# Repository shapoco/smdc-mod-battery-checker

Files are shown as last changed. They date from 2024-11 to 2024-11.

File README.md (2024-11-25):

# smdc-mod-battery-checker

[#SMD_Challenge](https://x.com/search?q=%23SMD_Challenge) の [基板](https://dominotech.blogspot.com/2024/08/smd-challenge-badge.html) を電池チェッカーに改造してみました。

## 機能

- プローブに接続された電池の残量を LED 5 個 x 点滅 4 段階 = 20 段階でレベル表示します。
- 1.5V、3V、3.7V、9V を判別し、それぞれの電圧範囲に応じてレベル表示します。
- プローブが開放状態のときは、起動後 3 秒間は自分自身の電池の電圧をレベル表示し、その後は元の SMD Challenge 基板と同様のアニメーションを表示します。

## 動作の様子

→ [x.com](https://twitter.com/shapoco/status/1860731428079857833)

## 回路

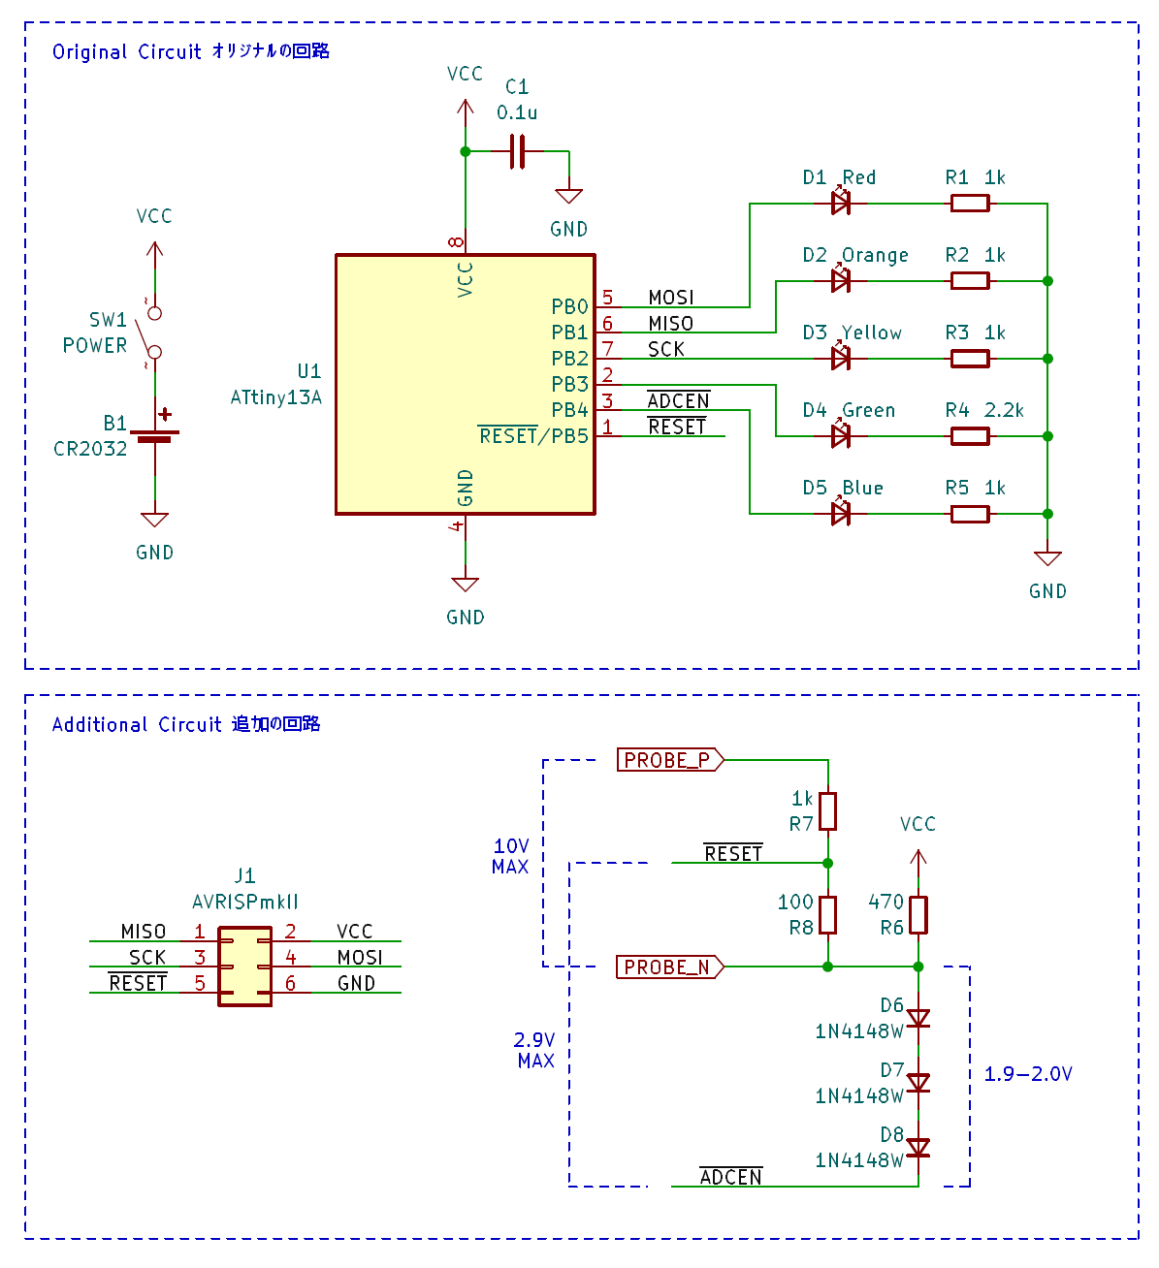
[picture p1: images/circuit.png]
回路図


## ヒューズ設定

600kHz で動作するように CKSEL=0b01 (4.8MHz)、CKDIV8=0b0 (クロックディバイダ有効) に設定しています。具体的な設定値は [fuse-write.ps1](firmware/tools/atprogram-win/fuse-write.ps1) を参照ください。

## ビルド手順

既に開発環境をお持ちであればそれを使って頂いてかまいません。

1. WSL に `gcc-avr`、`avr-libc`、`binutils-avr` をインストールします。
    - 参考: [avr-gcc と make だけで C/C++ AVR 環境構築 (ATmega328P) #Make - Qiita](https://qiita.com/BerandaMegane/items/740c75393b8fbfde5bed)
2. WSL 内で本リポジトリを clone し、`firmware/` の配下で `make` を実行します。
    - `firmware/build/battery_checker.elf` が生成されます。

## 書き込み手順

既に書き込み用のケーブルやツールをお持ちであればそれを使って頂いてかまいません。

1. Windows 環境に Microchip Studio をインストールします。
    - 書き込みに `C:\Program Files (x86)\Atmel\Studio\7.0\atbackend\atprogram.exe` を使用します。
2. AVRISP mkII を SMD Challenge 基板に接続します。
    - 環境によって `libusb-win32` のインストールが必要です。
3. WSL 内でリポジトリ配下の `firmware/` に移動します。
4. `make fuse-write` でヒューズを書き込みます。
5. `make flash-write` でプログラムを書き込みます。

## 仕組み

空き端子となっていた PB5 (RESET) に追加の回路を接続し、PB5/RESET と兼用の ADC0 を使って電圧を測定します。

PB5 にそのままアナログ電圧を入力すると電圧によってはリセットがかかってしまうので、1N4148W の順方向電圧降下 (Vf) x3 で 2V 程度の下駄を履かせ、そこを基準 (0V) として測定します。9V まで測定できるよう、抵抗分圧して入力しています。

1N4148W のカソードをそのまま GND に落とすと起動時の PB5 の電圧がリセット閾値の上限 (0.9Vcc) を下回ってしまいリセットが解除されない可能性があるため、GND ではなく PB4 に接続し、ADC0 を使う間は Low にドライブします。2V 程度ではリセットがかからないことを期待しています。

1N4148W の Vf は Vcc 電圧や環境温度で変動するため、起動時にプローブがオープンの状態で ADC 値を読み取り、1N4148W の I-V 特性から Vf と Vcc を推定します。Vcc や環境温度は時間とともに変化するため、プローブがオープンのときに定期的に更新します。

プローブに電池が接続されたときは Vf～Vcc の範囲をプローブ間の電圧に線形変換します。

## ダメなところ

- ATtiny13A のリセットの閾値電圧はデータシート上は 0.2Vcc ～ 0.9Vcc の範囲のどこかなので、そもそも使い方として正しくない。
- 1N4148W の個体差、Vcc 電圧、環境温度、PB4 の Low 電圧等の影響を受けるためデリケートすぎる。

----

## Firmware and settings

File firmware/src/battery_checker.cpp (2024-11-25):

#define F_CPU 600000ul

#include <avr/io.h>
#include <util/delay.h>
#include <stdint.h>

#define MIN(a, b) ((a) < (b) ? (a) : (b))
#define MAX(a, b) ((a) > (b) ? (a) : (b))
#define ROUND_DIV(a, b) (((a) + (b) / 2) / (b))

static constexpr int NUM_LEDS = 5;
static constexpr uint8_t LED_PIN_MASK = (1 << NUM_LEDS) - 1;

// 電圧の精度
static constexpr int VOLT_PREC = 12;
static constexpr uint16_t VOLT_ONE = 1ul << VOLT_PREC;

// レベル表示の階調
static constexpr uint8_t LEVEL_STEP = 4;
static constexpr uint8_t LEVEL_RANGE = NUM_LEDS * LEVEL_STEP;
static constexpr uint8_t LEVEL_MIN = 1;
static constexpr uint8_t LEVEL_MAX = LEVEL_MIN + LEVEL_RANGE - 1;

static constexpr uint16_t ADC_VCC = 1024;

// プローブ開放状態の ADC 値範囲
static constexpr uint16_t ADC_3XVF_MIN = 650; // VOLT_VCC_MAX に対応
static constexpr uint16_t ADC_3XVF_MAX = 774; // VOLT_VCC_MIN に対応

// VCC の電圧範囲
static constexpr uint16_t VOLT_VCC_MIN = 2.5f * VOLT_ONE; // ADC_3XVF_MAX に対応
static constexpr uint16_t VOLT_VCC_MAX = 3.2f * VOLT_ONE; // ADC_3XVF_MIN に対応

// プローブ開放判定の閾値電圧
static constexpr uint16_t VOLT_OPEN_MAX = 0.2f * VOLT_ONE;

// 1.5V 電池の電圧範囲
static constexpr uint16_t VOLT_1V5_MIN = 1.0f * VOLT_ONE;
static constexpr uint16_t VOLT_1V5_MAX = 1.6f * VOLT_ONE;

// 3V 電池の電圧範囲
static constexpr uint16_t VOLT_3V0_MIN = 2.5f * VOLT_ONE;
static constexpr uint16_t VOLT_3V0_MAX = 3.1f * VOLT_ONE;

// 3.7V 電池の電圧範囲
static constexpr uint16_t VOLT_3V7_MIN = 3.6f * VOLT_ONE;
static constexpr uint16_t VOLT_3V7_MAX = 4.2f * VOLT_ONE;

// 9V 電池の電圧範囲
static constexpr uint16_t VOLT_9V0_MIN = 7.0f * VOLT_ONE;
static constexpr uint16_t VOLT_9V0_MAX = 9.0f * VOLT_ONE;

// 入力分圧抵抗比
static constexpr uint8_t RDIV_HI = 10;
static constexpr uint8_t RDIV_LO = 1;

// 電圧レンジ
enum class VoltRange : uint8_t {
  OPEN,
  BAT_1V5,
  BAT_3V0,
  BAT_3V7,
  BAT_9V0,
};

// 開放時の ADC 値ヒストリ (Vcc 電圧推定用)
static constexpr uint8_t ADC_3XVF_SAMPLE_INTERVAL = 128;
static constexpr uint8_t ADC_3XVF_HISTORY_SIZE = 2;
static uint8_t adc3xVfSampleCounter = 0;
static uint16_t adc3xVfHistory[ADC_3XVF_HISTORY_SIZE];
static uint8_t adc3xVfHistoryIndex = 0;

// 電源電圧
static bool vccDetected = false;
static uint16_t voltVcc;

// 1N4148W の Vf * 3
static uint16_t volt3xVf;

// 電圧レンジヒストリ
static constexpr uint8_t RANGE_HISTORY_SIZE = 2;
static VoltRange rangeHistory[RANGE_HISTORY_SIZE];
static uint8_t rangeHistoryIndex = 0;
static VoltRange lastRange = VoltRange::OPEN;

// 各 LED のレベル値
static uint8_t ledValues[NUM_LEDS];

static constexpr int TARGET_FPS = 30;
static constexpr int LED_DRIVE_INTERVAL_MS = MAX(1, 1000 / TARGET_FPS / LEVEL_RANGE);
static constexpr int LED_BLINK_PERIOD_MS = 500;
static constexpr int LED_PHASE_STEP_CNTR_PERIOD = ROUND_DIV(LED_BLINK_PERIOD_MS, LED_DRIVE_INTERVAL_MS * LEVEL_RANGE);
static_assert(0 < LED_PHASE_STEP_CNTR_PERIOD && LED_PHASE_STEP_CNTR_PERIOD <= 255);
static uint8_t ledPhaseStepCntr = 0;
static uint8_t ledPhase = 0;

// 起動時の Vcc 電圧表示
static bool startup = true;

// 経過時間 (LED_BLINK_PERIOD_MS 単位, Max Hold)
static uint8_t tickCountMaxHold = 0;

// フリーランカウンタ (アニメーション用)
static uint8_t tickCountFreeRun = 0;

static void loop(void);
static void adc2Leds(uint16_t adcVal);
static void estimateVcc(uint16_t adcVal);
static uint16_t readAdcAverage(void);
static uint16_t readAdc(void);
static void volt2Leds(VoltRange range, uint16_t volt);
static void level2Leds(uint8_t level);
static void driveLeds(void);
static void lazyDelayMs(uint8_t duration);
static uint16_t unoffsetClip16u(uint16_t min, uint16_t range, uint16_t val);
static uint8_t cyclicIncr8u(uint8_t x, uint8_t period);

// x が 2 のべき乗か否か
#define IS_POW_OF_2_16U(x) \
    ((x) == (1u <<  0) || (x) == (1u <<  1) || (x) == (1u <<  2) || (x) == (1u <<  3) || \
     (x) == (1u <<  4) || (x) == (1u <<  5) || (x) == (1u <<  6) || (x) == (1u <<  7) || \
     (x) == (1u <<  8) || (x) == (1u <<  9) || (x) == (1u << 10) || (x) == (1u << 11) || \
     (x) == (1u << 12) || (x) == (1u << 13) || (x) == (1u << 14) || (x) == (1u << 15))

// x を 0 ～ (period-1) の間でサイクリックにインクリメントする
#define CYCLIC_INCR_8U(x, period) \
    (IS_POW_OF_2_16U(period) ? (((x) + 1) & ((period) - 1)) : cyclicIncr8u((x), (period)))

// 32bit x 16bit の乗算
#define mul32ux16u(a, b) ((uint32_t)(a) * (uint16_t)(b))

int main(void) {
    // GPIO 設定
    DDRB = LED_PIN_MASK; // PB0..4 を出力に設定
    PORTB = 0x00; // LOW 出力

    // ADC設定
    ADCSRA = 0b10000111;
    // [7]   ADEN  = 1    ADC有効
    // [6]   ADSC  = 0    ADC停止
    // [5]   ADATE = 0    オートトリガ無効
    // [4]   ADIF  = 0    割り込みなし
    // [3]   ADIE  = 0    割り込み無効
    // [2:0] ADPS  = 0    プリスケーラ: 128 (最大)
    ADMUX = 0x00;
    // [6]   REFS0 = 0    Vref = Vcc
    // [5]   ADLAR = 0    変換結果右寄せ
    // [1:0] MUX   = 0    ADC0 (PB5) 選択
    DIDR0 |= _BV(ADC0D); // ADC0 のデジタル入力無効化

    // ループ処理開始
    while(true) loop();
}

static void loop(void) {
    uint16_t adcVal = readAdcAverage();

    if (!vccDetected) { // Vcc 電圧推定前
        if (ADC_3XVF_MIN - 50 <= adcVal && adcVal < ADC_3XVF_MAX + 50) {
            // 初回測定値でヒストリを埋める
            for(int i = 0; i < ADC_3XVF_HISTORY_SIZE; i++) {
                adc3xVfHistory[i] = adcVal;
            }
            // 初期 Vcc 電圧推定
            estimateVcc(adcVal);
            vccDetected = true;
            tickCountMaxHold = 0;
            tickCountFreeRun = 0;
            ledPhase = 0;
        }
        else {
            level2Leds(ledPhase >= LEVEL_STEP / 2 ? 0 : LEVEL_MAX);
        }
    }
    else { // Vcc 電圧推定後
        adc2Leds(adcVal);
    }
    
    driveLeds();
}

// ADC 値から電圧に変換し LED に反映する
static void adc2Leds(uint16_t adcVal) {
    // ADC値から電圧へ変換
    uint16_t volt = mul32ux16u(adcVal, voltVcc) / ADC_VCC;
    volt = (volt >= volt3xVf) ? (volt - volt3xVf) : 0;
    volt = mul32ux16u(volt, RDIV_HI + RDIV_LO) / RDIV_LO;

    // レンジ判定 (雑でよいので 8bit に縮めて処理する)
    constexpr uint16_t VOLT_DIV = 1u << (VOLT_PREC - 4);
    constexpr uint8_t THRESH_1V5 = ROUND_DIV(VOLT_1V5_MAX + VOLT_3V0_MIN, 2 * VOLT_DIV);
    constexpr uint8_t THRESH_3V0 = ROUND_DIV(VOLT_3V0_MAX + VOLT_3V7_MIN, 2 * VOLT_DIV);
    constexpr uint8_t THRESH_3V7 = ROUND_DIV(VOLT_3V7_MAX + VOLT_9V0_MIN, 2 * VOLT_DIV);
    static_assert((15 * VOLT_ONE + VOLT_DIV / 2) / VOLT_DIV < 256);
    uint8_t voltDiv = ROUND_DIV(volt, VOLT_DIV);
    VoltRange range;
    if (volt < VOLT_OPEN_MAX) {
        range = VoltRange::OPEN;
    }
    else if (voltDiv <= THRESH_1V5) {
        range = VoltRange::BAT_1V5;
    }
    else if (voltDiv <= THRESH_3V0) {
        range = VoltRange::BAT_3V0;
    }
    else if (voltDiv <= THRESH_3V7) {
        range = VoltRange::BAT_3V7;
    }
    else {
        range = VoltRange::BAT_9V0;
    }

    // チャタリング除去
    bool stable = true;
    for (uint8_t i = 0; i < RANGE_HISTORY_SIZE; i++) {
        stable &= (range == rangeHistory[i]);
    }
    rangeHistory[rangeHistoryIndex] = range;
    rangeHistoryIndex = CYCLIC_INCR_8U(rangeHistoryIndex, RANGE_HISTORY_SIZE);
    if (!stable) return;
    
    // レンジの変化検出
    if (range != lastRange) {
        ledPhase = 0;
        tickCountMaxHold = 0;
        tickCountFreeRun = 0;
    }
    lastRange = range;

    // 表示の更新
    if (range == VoltRange::OPEN) { // 電池未接続時
        // Vcc 電圧や温度変化で基準電圧が変動するので定期的に更新する
        adc3xVfSampleCounter = CYCLIC_INCR_8U(adc3xVfSampleCounter, ADC_3XVF_SAMPLE_INTERVAL);
        if (adc3xVfSampleCounter == 0) {
            estimateVcc(adcVal);
        }

        constexpr uint8_t STARTUP_TIME_TICK = 3000 / LED_BLINK_PERIOD_MS;
        if (startup && tickCountMaxHold < STARTUP_TIME_TICK) {
            // 起動後は Vcc 電圧を表示
            volt2Leds(VoltRange::BAT_3V0, voltVcc);
        }
        else {
            startup = false;
            // 待機アニメーション
            level2Leds(0);
            uint8_t p = tickCountFreeRun & 0x7;
            if (p & 0x4) p = 8 - p;
            ledValues[p] = LEVEL_STEP;
        }
    }
    else { // 電池接続時
        startup = false;
        constexpr uint8_t RANGE_DISP_TICK = 1000 / LED_BLINK_PERIOD_MS;
        if (tickCountMaxHold < RANGE_DISP_TICK) {
            // 最初は電圧レンジを表示
            level2Leds(0);
            ledValues[(int)range] = LEVEL_STEP;
        }
        else {
            // 電池電圧表示
            volt2Leds(range, volt);
        }
    }
}

// 1N4148W の Vf * 3 から Vcc 電圧を推定
static void estimateVcc(uint16_t adcVal) {
    // ヒストリの最低値
    uint16_t adcOpen = adcVal;
    for(uint8_t i = 0; i < ADC_3XVF_HISTORY_SIZE; i++) {
        adcOpen = MIN(adc3xVfHistory[i], adcOpen);
    }

    // ヒストリの更新
    adc3xVfHistoryIndex = CYCLIC_INCR_8U(adc3xVfHistoryIndex, ADC_3XVF_HISTORY_SIZE);
    adc3xVfHistory[adc3xVfHistoryIndex] = adcVal;

    // Vcc 電圧推定
    constexpr uint16_t ONE = 1u << 8;
    constexpr uint32_t SLOPE = (uint32_t)ONE * (VOLT_VCC_MAX - VOLT_VCC_MIN) / (ADC_3XVF_MAX - ADC_3XVF_MIN);
    uint16_t tmp = adcOpen;
    if (tmp > ADC_3XVF_MAX) tmp = 0;
    else if (tmp < ADC_3XVF_MIN) tmp = (ADC_3XVF_MAX - ADC_3XVF_MIN);
    else tmp = ADC_3XVF_MAX - tmp;
    voltVcc = (uint16_t)(mul32ux16u(SLOPE, tmp) / ONE) + VOLT_VCC_MIN;

    // 1N4148W の Vf * 3 の推定
    volt3xVf = mul32ux16u(voltVcc, adcOpen) / ADC_VCC;
}

// ADC 値を何回か読み取って平均を返す
static uint16_t readAdcAverage(void) {
    constexpr uint8_t NUM_SAMPLES = 8;
#if 0
    // ダイナミック点灯を PB4-->PB0 の順にしたので PB4 は十分に長い時間 Low になっているはず
    PORTB = 0x00;
    lazyDelayMs(1);
#endif
    readAdc(); // 読み捨て
    uint16_t adcVal = 0;
    for (uint8_t i = 0; i < NUM_SAMPLES; i++) {
        adcVal += readAdc();
    }
    return ROUND_DIV(adcVal, NUM_SAMPLES);
}

// ADC 値を 1 回読み取る
static uint16_t readAdc(void) {
    ADCSRA |= _BV(ADSC); // ADC開始
    loop_until_bit_is_set(ADCSRA, ADIF); // ADC完了待ち
    uint8_t lo = ADCL; // Low 側から先に読むこと
    uint16_t hi = ((uint16_t)ADCH) << 8;
    return hi | lo;
}

// 電圧値を LED に反映
static void volt2Leds(VoltRange range, uint16_t volt) {
    constexpr uint16_t ONE = VOLT_ONE;
    constexpr uint16_t RANGE_1V5  = VOLT_1V5_MAX - VOLT_1V5_MIN;
    constexpr uint16_t RANGE_3V0  = VOLT_3V0_MAX - VOLT_3V0_MIN;
    constexpr uint16_t RANGE_3V7  = VOLT_3V7_MAX - VOLT_3V7_MIN;
    constexpr uint16_t RANGE_9V0  = VOLT_9V0_MAX - VOLT_9V0_MIN;
    constexpr uint8_t SLOPE_1V5  = ROUND_DIV((uint32_t)ONE * LEVEL_RANGE, RANGE_1V5);
    constexpr uint8_t SLOPE_3V0  = ROUND_DIV((uint32_t)ONE * LEVEL_RANGE, RANGE_3V0);
    constexpr uint8_t SLOPE_3V7  = ROUND_DIV((uint32_t)ONE * LEVEL_RANGE, RANGE_3V7);
    constexpr uint8_t SLOPE_9V0  = ROUND_DIV((uint32_t)ONE * LEVEL_RANGE, RANGE_9V0);
    uint8_t slope = 0;
    uint16_t vrange = 0;
    uint16_t vmin = 0;
    switch(range) {
    case VoltRange::BAT_1V5: 
        slope = SLOPE_1V5;
        vmin = VOLT_1V5_MIN;
        vrange = RANGE_1V5;
        break;

    case VoltRange::BAT_3V0:
        slope = SLOPE_3V0;
        vmin = VOLT_3V0_MIN;
        vrange = RANGE_3V0;
        break;

    case VoltRange::BAT_3V7:
        slope = SLOPE_3V7;
        vmin = VOLT_3V7_MIN;
        vrange = RANGE_3V7;
        break;

    //case VoltRange::BAT_9V0:
    default:
        slope = SLOPE_9V0;
        vmin = VOLT_9V0_MIN;
        vrange = RANGE_9V0;
        break;
    }
    
    volt = unoffsetClip16u(vmin, vrange, volt);
    uint8_t level = LEVEL_MIN;
    level += mul32ux16u(slope, volt) / ONE;
    level2Leds(level);
}

static void level2Leds(uint8_t level) {
    int8_t tmp = level;
    for (uint8_t iled = 0; iled < NUM_LEDS; iled++) {
        int8_t val = tmp;
        if (val < 0) {
            val = 0;
        }
        else if (val >= LEVEL_STEP) {
            val = LEVEL_STEP;
        }
        ledValues[iled] = val;
        tmp -= LEVEL_STEP;
    }
}

static void driveLeds(void) {
    ledPhaseStepCntr = CYCLIC_INCR_8U(ledPhaseStepCntr, LED_PHASE_STEP_CNTR_PERIOD);
    uint8_t phase = ledPhase;
    if (ledPhaseStepCntr == 0) {
        ledPhase = CYCLIC_INCR_8U(phase, LEVEL_STEP);
        if (ledPhase == 0 && tickCountMaxHold < 255) {
            tickCountMaxHold++;
        }
        tickCountFreeRun++;
    }

    uint8_t iled = NUM_LEDS;
    uint8_t ledMask = 1u << (NUM_LEDS - 1);
    while (iled-- != 0) {
        if (phase < ledValues[iled]) {
            PORTB = ledMask;
        }
        ledMask >>= 1;
        lazyDelayMs(LED_DRIVE_INTERVAL_MS);
        PORTB = 0x00;
    }
}

// なんとなく 1ms くらいのディレイ
static void lazyDelayMs(uint8_t duration) {
    while (duration-- > 0) {
        for (uint8_t i = 0; i < 100; i++) {
            asm volatile ("nop");
        }
    }
}

// オフセット除去 + クリッピング
static uint16_t unoffsetClip16u(uint16_t min, uint16_t range, uint16_t val) {
    if (val < min) return 0;
    val -= min;
    if (val > range) return range;
    return val;
}

// CYCLIC_INCR_8U の period が 2 のべき乗でない時用
static uint8_t cyclicIncr8u(uint8_t x, uint8_t period) {
    return (x + 1 < period) ? x + 1 : 0;
}

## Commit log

2024-11-24 support 3.7V battery
2024-11-24 optimize footprint (950B)
2024-11-24 fixbug for 9V (954B)
    [battery_checker.cpp]
2024-11-24 optimize footprint (944B)
2024-11-24 optimize footprint (940B)
2024-11-24 optimize footprint (886B)
2024-11-24 optimize footprint (870B)
2024-11-25 fix comments and func names (1020B)
    [battery_checker.cpp]
